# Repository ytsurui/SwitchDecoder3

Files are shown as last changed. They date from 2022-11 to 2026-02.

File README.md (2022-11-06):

# SwitchDecoder3

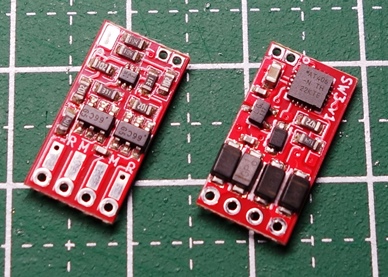
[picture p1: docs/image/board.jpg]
PCB Preview


NMRA DCC規格のアクセサリパケットを受信して、直流二線式のポイント線路を動作させることができるアクセサリデコーダです。

本リポジトリには、基板設計データとファームウェア、動作確認用ファームウェアが含まれています。

## 開発環境

- KiCad 6.0.8
- Microchip Studio Version 7.0.2542

## 主要スペック

  * 組み立て後の基板サイズ: 15.5mm x 8.0mm
  * 推奨最大電圧: 16V
  * 出力電流: 最大2A (ピーク3A)
  * マイコン書き込み端子を用意し、実装後のプログラム書き換えも可能
    <br>UPDI 2pin Interface (GND / UPDI)

## 通常ファームウェア (Firmware)

設定したアクセサリアドレスに応じたDCCパケットを受信すると、ポイント線路を動作させます。

通電開始時にPROG端子に取り付けた配線をどちらかの線路に接触させることで、プログラムモードで起動します。

プログラムモードで起動している間に、同一のアクセサリアドレスに対する操作を連続して3回以上送信することで、設定されているアクセサリアドレスを送信したものに変更することができます。

また、CV値の書き込みにより、通電時間や通電開始までの遅延時間など、細かい動作の調整や、設定のリセットも可能です。

## 動作確認用ファームウェア (Firm_Test)

アクセサリアドレス「1」固定でDCCパケットを受信して動作できる機能と、PROG端子を線路に接触させると約1秒おきにポイント線路の転換動作を行うようにプログラムを作成してあります。

このファームウェアを書き込むことで、SwitchDecoder3基板のDCC入力、PROG端子、モータードライバ回路のすべてをテストすることができます。
  
## 各種ドキュメント

  * [マイコンのピンアサイン](docs/pin.md)
  * [パーツリスト](docs/partslist.md)
  * [CV値一覧](docs/cv_list.md)
  * [AVR Fuse Bitの設定内容](docs/avrfuse.md)

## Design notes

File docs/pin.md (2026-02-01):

# Microcontroller Pin Assign

<table>
  <tr><th>Function</th><th>Pin Name</th><th>Input/Output</th><th>ATtiny806<br>(VQFN) Pin Num</th><th>ATtiny806<br>(SOIC) Pin Num</th></tr>
  <tr><td>UPDI Programming Interface</td><td>PA0</td><td>-</td><td>19</td><td>16</td></tr>
  <tr><td>Power</td><td>Vcc</td><td>-</td><td>4</td><td>1</td></tr>
  <tr><td>Power</td><td>GND</td><td>-</td><td>3</td><td>20</td></tr>
  
  <tr><td>DCC Input Rail+</td><td>PB4</td><td>Input</td><td>10</td><td>7</td></tr>
  <tr><td>DCC Input Rail-</td><td>PA4</td><td>Input</td><td>1</td><td>18</td></tr>

  <tr><td>Motor Driver Forward Signal</td><td>PA4</td><td>Output</td><td>5</td><td>2</td></tr>
  <tr><td>Motor Driver Backward Signal</td><td>PA5</td><td>Output</td><td>6</td><td>3</td></tr>
  <tr><td>Motor Driver PWM Signal</td><td>PB0</td><td>Output<br>(Timer A)</td><td>14</td><td>11</td></tr>

  <tr><td>Turnout Direction LED Closed (LED+)</td><td>PC2</td><td>Output</td><td>17</td><td>14</td></tr>
  <tr><td>Turnout Direction LED Thrown (LED-)</td><td>PC3</td><td>Output</td><td>18</td><td>15</td></tr>

</table>

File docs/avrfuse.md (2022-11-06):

## AVR Fuse Bitの設定内容

BODを有効にするため、下記の内容を書きます。
<br>(表記はAtmel Studioのものとなります)

  * APPEND: 0x00
  * BODCFG: 0x04
  * BOOTEND: 0x00
  * OSCCFG: 0x02
  * SYSCFG0: 0xF6
  * SYSCFG1: 0x07
  * WDTCFG: 0x00

Atmel Studioで設定を行う場合、「BODCFG.ACTIVE」を「Enabled」に切り替えてください。

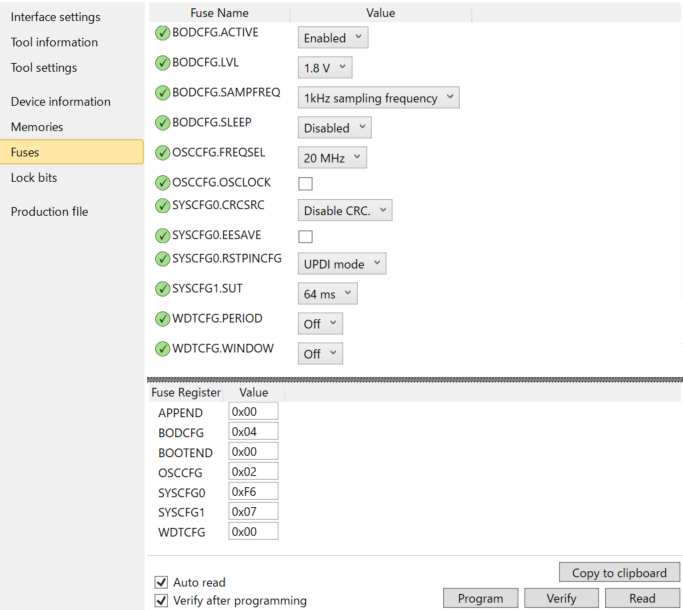
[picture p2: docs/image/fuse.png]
AVR Fuse Programming


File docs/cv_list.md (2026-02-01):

# SwitchDecoder3 CV値一覧

<table>

  <tr><th>CV番号</th><th>初期値</th><th>内容</th></tr>
  <tr><td>1</td><td>129 (0x81)</td><td>アクセサリアドレス 下位ビット</td></tr>
  <tr><td>7</td><td>-</td><td>ファームウェアバージョン番号</td></tr>
  <tr><td>8</td><td>13</td><td>メーカーID<br>(8 または 13を書き込むことでデコーダ設定のリセット)</td></tr>
  <tr><td>9</td><td>248 (0xF8)</td><td>アクセサリアドレス 上位ビット</td></tr>
  <tr><td>33</td><td>0 (0x00)</td>
    <td>デコーダ動作制御
      <br>
      <br>0ビット (0x01) : 転換方向(直進/分岐) 逆転
      <br>1ビット (0x02) : プログラム端子 無効化
      <br>2-4ビット: 自動ロック・自動動作モードの動作
      <br>  000: 無効
      <br>  001: 通過後、C方向に自動的に戻す
      <br>  010: 通過後、T方向に自動的に戻す
      <br>  011: 通過後、違う方向に転換する (トグル動作)
      <br>  100: 通過時のみ動作ロック
      <br>  101: 通過時ロック / C方向に自動的に戻す
      <br>  110: 通過時ロック / T方向に自動的に戻す
      <br>  111: 通過時ロック / 通過後、違う方向に転換する (トグル動作)
      </td>
  </tr>
  <tr><td>34</td><td>63 (0x3F)</td><td>通電時間 下位8ビット<br>(63msec = 0.063sec)</td></tr>
  <tr><td>35</td><td>0 (0x00)</td><td>通電時間 上位8ビット</td></tr>
  <tr><td>36</td><td>0 (0x00)</td><td>通電開始遅延時間 下位8ビット</td></tr>
  <tr><td>37</td><td>0 (0x00)</td><td>通電開始遅延時間 上位8ビット</td></tr>
  <tr><td>39</td><td>208 (0xD0)</td><td>自動ロックモード ロック解除時間 下位8ビット</td></tr>
  <tr><td>40</td><td>7 (0x07)</td><td>自動ロックモード ロック解除時間 上位8ビット</td></tr>
  <tr><td>41</td><td>136 (0x88)</td><td>自動動作モード 動作時間 下位8ビット</td></tr>
  <tr><td>42</td><td>19 (0x13)</td><td>自動動作モード 動作時間 上位8ビット</td></tr>
  <tr><td>43</td><td>1 (0x01)</td><td>分岐方向LEDのオン・オフ (0=オフ / 1=オン)
</table>

---

## 通電時間・動作遅延時間・自動ロックモード時間・自動動作モード時間について

上位8ビット + 下位8ビットの合計 x 1ミリ秒で時間を設定できます。
<br>例えば、通電時間は初期値のCV34=200、CV35=0の場合、200ミリ秒=0.2秒となります。
<br>CV34=232、CV35=3と設定すると、(3 * 256) + 232 = 1000となり、1000ミリ秒=1秒となります。

動作遅延時間を設定すると、ポイント切り替え指令を受け取った後、指定した時間が経過してから通電を開始するようになります。

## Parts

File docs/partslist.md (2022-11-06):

# SwitchDecoder3 Parts List

<table>
  <tr><th></th><th>Name</th><th>Count</th></th>
  <tr><td>C1,C5</td><td>GRM155F11E104ZA01<br>(0.1uF 25V 1005)</td><td>2</td></tr>
  <tr><td>C3</td><td>GRM188R60J226MEA0<br>(22uF 6.3V 1608)</td><td>1</td></tr>
  <tr><td>C7</td><td>GRM155R11H103KA88<br>(0.01uF 50V 1005)</td><td>1</td></tr>
  <tr><td>D1-D4</td><td>SS2040FL<br>(Schottky Diode, 2A 40V)</td><td>4</td></tr>
  <tr><td>D5</td><td>UDZV5.1B<br>(Zener Diode, 5.1V 200mW)</td><td>1</td></tr>
  <tr><td>Q1,Q2</td><td>DMG6602LVT<br>(Nch+Pch Dual MOSFET, SOT23-6)</td><td>2</td></tr>
  <tr><td>Q3</td><td>PMBT3904VS,115<br>(NPN Dual Transistor, SOT666)</td><td>1</td></tr>
  <tr><td>Q5</td><td>2SC4116<br>(NPN General Purpose Transistor, SC-70)</td><td>1</td></tr>
  <tr><td>R1,R2,R17,R18</td><td>100k ohm 1.6mm x 0.8mm</td><td>4</td></tr>
  <tr><td>R3,R4,R7,R8</td><td>1k ohm 1.6mm x 0.8mm</td><td>4</td></tr>
  <tr><td>R5,R6</td><td>330 ohm 1.6mm x 0.8mm</td><td>2</td></tr>
  <tr><td>R12</td><td>4.7k ohm 1.6mm x 0.8mm</td><td>1</td></tr>
  <tr><td>U2</td><td>ATtiny406<br>ATtiny806</td><td>1</td></tr>
</table>

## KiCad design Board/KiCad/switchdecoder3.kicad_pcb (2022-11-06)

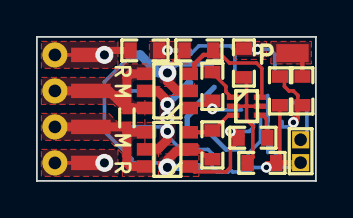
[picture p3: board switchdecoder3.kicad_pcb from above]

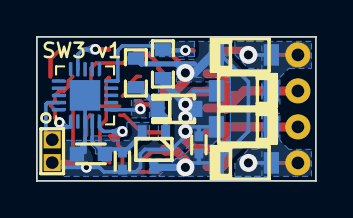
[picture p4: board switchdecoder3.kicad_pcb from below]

Board: 2 copper layers, 15.5 x 8.0 mm, 32 parts (13 on the bottom side), 20 nets.

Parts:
C1, C5: 104; C_1005
C3: 226; C_1608
C7: 182; C_1005
D1, D2, D3, D4: SS2040FL; PMDU
D5: UDZV5.1B; UMD2
P1, P2, P3, P4: PAD; PAD_2.2x0.8_SMD
P7: PROG; PAD_PROG_2PIN_HOLE0.7
P10: Test; Test_4pin_2mm
P11: PROG_PAD; PAD_1.0x1.8_SMD
Q1, Q2: DMG6601LVT; SOT-23-6
Q3: PMBT3904VS; SOT-666-nomark
Q5: 2SC4116; SC-70_v2
R1, R2, R17, R18: 104; R_1608
R3, R4, R7, R8: 102; R_1608
R5, R6: 331; R_1608
R12: 472; R_1608
U2: ATtiny406-M; VQFN-20-1EP_3x3mm_P0.4mm_EP1.7x1.7mm

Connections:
+5V: C3.1, C5.1, Q5.2 (E), U2.4 (VCC)
+12V: C1.1, D1.1 (K), D3.1 (K), Q1.2 (S), Q2.2 (S), Q5.3 (C), R3.1, R4.1, R12.1
/PROG: P11.1, R2.1
FWD: Q2.1 (G), R6.2, U2.5 (PA4)
GND: C1.2, C3.2, C5.2, D2.2 (A), D4.2 (A), D5.2 (A), P7.2, Q1.5 (S), Q2.5 (S), R8.2, R17.2, R18.2, U2.3 (GND), U2.21 (GND)
MOTOR+: C7.1, P3.1, P10.2, Q1.4 (D), Q1.6 (D)
MOTOR-: C7.2, P4.1, P10.3, Q2.4 (D), Q2.6 (D)
unnamed: D5.1 (K), Q5.1 (B), R12.2
unnamed: Q1.3 (G), Q3.6 (C1), R3.2
unnamed: Q2.3 (G), Q3.3 (C2), R4.2
unnamed: Q3.1 (E1), R5.1
unnamed: Q3.2 (B1), Q3.5 (B2), R7.2, R8.1
unnamed: Q3.4 (E2), R6.1
unnamed: R1.2, R17.1, U2.10 (PB4)
unnamed: R2.2, R18.1, U2.1 (PA2)
PWM: R7.1, U2.14 (PB0)
RAIL+: D1.2 (A), D2.1 (K), P1.1, P10.1, R1.1
RAIL-: D3.2 (A), D4.1 (K), P2.1, P10.4
REV: Q1.1 (G), R5.2, U2.6 (PA5)
UPDI: P7.1, U2.19 (~RESET/PA0)

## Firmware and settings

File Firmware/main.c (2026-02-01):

/*
 * main.c
 *
 * Created: 2022/09/16 18:25:00
 * Author : Y.Tsurui
 */ 

#include <avr/io.h>

#include "cpuclk.h"
#include "cpu_wdt.h"
#include "rtc.h"

#include "dcc_poller.h"
#include "dcc_packet_exec.h"
#include "prog_port.h"

#include "sw_config.h"
#include "sw_driver.h"
#include "sw_led.h"

int main(void)
{
	uint8_t dccRecvPacketCache[48];
	uint8_t dccRecvPacketLength;
	
	setCLK();
	startWDT();
	initRTC();
	
	initProgPort();
	initDCCpoller();
	initSWdriver();
	initLEDdriver();
	
	initConfig();
	
	while (loadCVevent()) {
		clearWDT();
		dccPacketShifter(&dccRecvPacketLength, dccRecvPacketCache);
	}
	
	
    /* Replace with your application code */
    while (1) 
    {
		taskProgMode();
		
		clearWDT();
		dccPacketShifter(&dccRecvPacketLength, dccRecvPacketCache);
		
		if (dccRecvPacketLength) {
			dccPacketRouter(dccRecvPacketLength, dccRecvPacketCache);
			dccRecvPacketLength = 0;
		}
		
		if (chkRTCflag()) {
			clkReceiverSWdriver();
			clkReceiverProgPort();
			dccRouterClockReceiver();
		}
    }
}

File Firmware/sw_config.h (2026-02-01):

/*
 * sw_config.h
 *
 * Created: 2022/09/17 0:09:12
 *  Author: Y.Tsurui
 */ 

void initConfig(void);

uint8_t loadCVevent(void);

uint8_t read_cv_byte(uint16_t CVnum);
void write_cv_byte(uint16_t CVnum, uint8_t data);

uint8_t chk_addr(uint8_t addr1_data, uint8_t addr2_data);
uint8_t write_addr(uint8_t addr1_data, uint8_t addr2_data);

uint16_t getTurnOnTime(void);
uint16_t getTurnOnDelayTime(void);
uint8_t getConfigureBytes(void);

uint16_t getLockTime(void);
uint16_t getAutoMoveTime(void);

uint8_t getDirectionLEDenable(void);

#define CONFIG_BIT_REVERSE			0x01
#define CONFIG_BIT_DISABLEPROGPORT	0x02

#define CONFIG_SENSORMODE_MASK	0x1C
#define CONFIG_SENSORMODE_LOCK_MASK	0x10

#define CONFIG_SENSORMODE_DISABLE 0

#define CONFIG_SENSORMODE_NONLOCK_AUTO_C		4
#define CONFIG_SENSORMODE_NONLOCK_AUTO_T		8
#define CONFIG_SENSORMODE_NONLOCK_AUTOCHANGE	12

#define CONFIG_SENSORMODE_LOCK_ONLY			16
#define CONFIG_SENSORMODE_LOCK_AUTO_C		20
#define CONFIG_SENSORMODE_LOCK_AUTO_T		24
#define CONFIG_SENSORMODE_LOCK_AUTOCHANGE	28

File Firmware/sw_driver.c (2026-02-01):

/*
 * sw_driver.c
 *
 * Created: 2022/09/16 21:59:43
 *  Author: Y.Tsurui
 */ 

#include <avr/io.h>
#include "sw_driver.h"
#include "sw_config.h"
#include "sw_led.h"
#include "prog_port.h"

uint16_t switchTimerCounter = 0;
uint16_t delayTimer = 0;

uint8_t waitMode = 0;
uint16_t waitTime = 0;

uint8_t basicACKflag = 0;
uint8_t basicACKcounter = 0;
#define BASIC_ACK_COUNT_MAX	10

#define LAST_SWITCH_STAT_C	0
#define LAST_SWITCH_STAT_T	1

uint8_t lastSwitchStat = LAST_SWITCH_STAT_C;

void initSWdriver(void) {
	PORTA.DIRSET = PIN4_bm | PIN5_bm;
	PORTB.DIRSET = PIN0_bm;
	
	PORTA.OUTCLR = PIN4_bm | PIN5_bm;
	PORTB.OUTCLR = PIN0_bm;
}


void clkReceiverSWdriver(void)
{	
	if (basicACKcounter) {
		basicACKcounter++;
		if (basicACKcounter >= BASIC_ACK_COUNT_MAX) {
			basicACKcounter = 0;
			//basicACKflag = 0;
			PORTA.OUTCLR = PIN4_bm | PIN5_bm;
			PORTB.OUTCLR = PIN0_bm;
		}
		return;
	}
	
	
	if (delayTimer) {
		delayTimer--;
		if (delayTimer == 0) {
			PORTB.OUTSET = PIN0_bm;
		}
		return;
	}
	
	if (switchTimerCounter) {
		switchTimerCounter--;
	}
	
	if (switchTimerCounter == 0) {
		PORTA.OUTCLR = PIN4_bm | PIN5_bm;
		PORTB.OUTCLR = PIN0_bm;
	}
	
	if (waitMode > 0) {
		if (readLockStat() == 0) {
			setSwitch(waitMode, waitTime);
			waitMode = 0;
			waitTime = 0;
		}
		return;
	}
}

void setSwitch(uint8_t dir, uint16_t ms)
{
	if (readLockStat()) {
		waitMode = dir;
		waitTime = ms;
		return;
	}
	
	PORTB.OUTCLR = PIN0_bm;
	
	if (getConfigureBytes() & CONFIG_BIT_REVERSE) {
		PORTA.OUTCLR = PIN4_bm;
		PORTA.OUTCLR = PIN5_bm;
		if (dir == SW_DIR_CLOSE) {
			PORTA.OUTSET = PIN4_bm;
			lastSwitchStat = LAST_SWITCH_STAT_C;
		} else if (dir == SW_DIR_THROWN) {
			PORTA.OUTSET = PIN5_bm;
			lastSwitchStat = LAST_SWITCH_STAT_T;
		}
	} else {
		PORTA.OUTCLR = PIN4_bm;
		PORTA.OUTCLR = PIN5_bm;
		if (dir == SW_DIR_CLOSE) {
			PORTA.OUTSET = PIN5_bm;
			lastSwitchStat = LAST_SWITCH_STAT_C;
		} else if (dir == SW_DIR_THROWN) {
			PORTA.OUTSET = PIN4_bm;
			lastSwitchStat = LAST_SWITCH_STAT_T;
		}
	}
	
	setLED(dir);
	
	delayTimer = getTurnOnDelayTime();
	if (delayTimer == 0) {
		PORTB.OUTSET = PIN0_bm;
	}
	
	switchTimerCounter = ms;
}

void toggleSwitch(uint16_t ms)
{
	if (lastSwitchStat == LAST_SWITCH_STAT_T) {
		// T to C
		setSwitch(SW_DIR_CLOSE, ms);
	} else {
		// C to T
		setSwitch(SW_DIR_THROWN, ms);
	}
}

void basicACK()
{
	basicACKcounter = 1;
	basicACKflag = 1;
	
	PORTA.OUTCLR = PIN4_bm;
	PORTB.OUTCLR = PIN0_bm;
	PORTA.OUTCLR = PIN5_bm;
	PORTA.OUTSET = PIN4_bm;
	PORTB.OUTSET = PIN0_bm;
}

void basicACKoff()
{
	basicACKcounter = 0;
	PORTA.OUTCLR = PIN4_bm | PIN5_bm;
	PORTB.OUTCLR = PIN0_bm;
}

uint8_t readBasicACKflag()
{
	return basicACKflag;
}

void clearBasicACKflag()
{
	basicACKflag = 0;
}

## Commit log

2023-01-14 一部コマンドステーションでBiDiを有効にしている場合、パケットを認識しない問題を修正
2023-01-14 設定値読み出し中のDCCパケット受信に対応
2023-01-14 ポイント転換方向を修正
2023-01-14 バージョンコードを2に変更
2023-01-14 Service ModeのACK応答を調整
2024-03-21 receive cacheの処理を変更
2024-03-21 Lock Modeの設定を追加
2024-03-21 Lock Modeの動作を追加
2024-03-21 CVリスト: 自動ロックモード関連のCV説明を追加
2024-03-23 ロック時間と自動動作時間の分離
2024-03-23 通過時ロック・自動動作分離をCV一覧に反映
2025-12-30 LED表示を追加
2025-12-30 ドキュメントにLED関連を追加
2026-02-01 メモリ破壊バグを修正
2026-02-01 DCCバイトの判定時間を修正
2026-02-01 CV34の初期値を変更
